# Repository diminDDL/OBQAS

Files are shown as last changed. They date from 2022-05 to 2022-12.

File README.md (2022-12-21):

# OBQAS
Open Battery Quantification and Analysis System

A high efficiency high power imax alternative.

Features include:

* up to 5 Li-ion cells (22 Vout max)

Supported battery types:
* Li-ion (with balancing)
* Ni-mh
* Ni-cd
* Pb
* More...

Ratings:
* Maximum output voltage - 22V
* Maximum charging current - 5A
* Maximum charging power: ~100W

Discharge:
* Maximum input voltage - 22V
* Maximum discharging current - 3A (up to 5A with a better MOSFET)
* Maximum discharging power: ~75W

Input voltage:
12-24V

Topology:
buck-boost synchronous (TPS55288)

Additional features:
20x4 display with encoder
USB-C for data logging and remote control/outputs 5V 1A
SD card holds configuration parameters/standalone data logging
Thermocopule for battery monitoring
ESP32 - WiFI/BLE

### Pictures
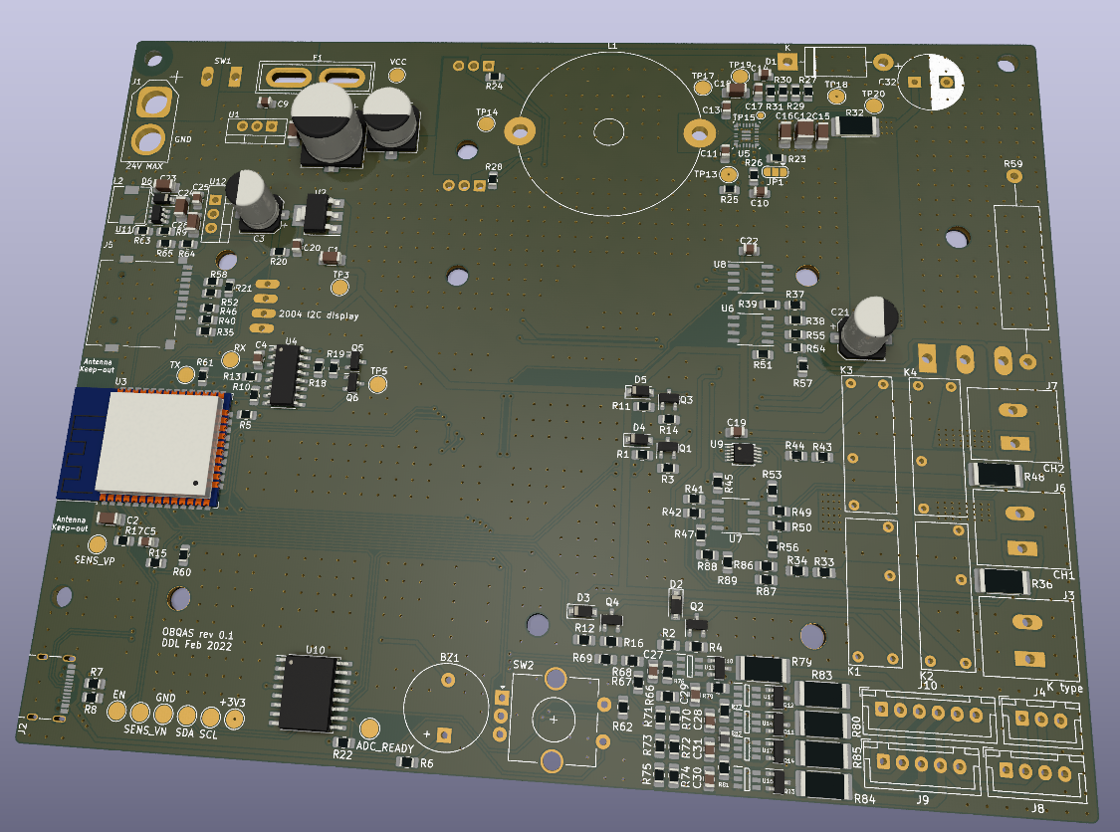
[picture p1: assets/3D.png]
3D render


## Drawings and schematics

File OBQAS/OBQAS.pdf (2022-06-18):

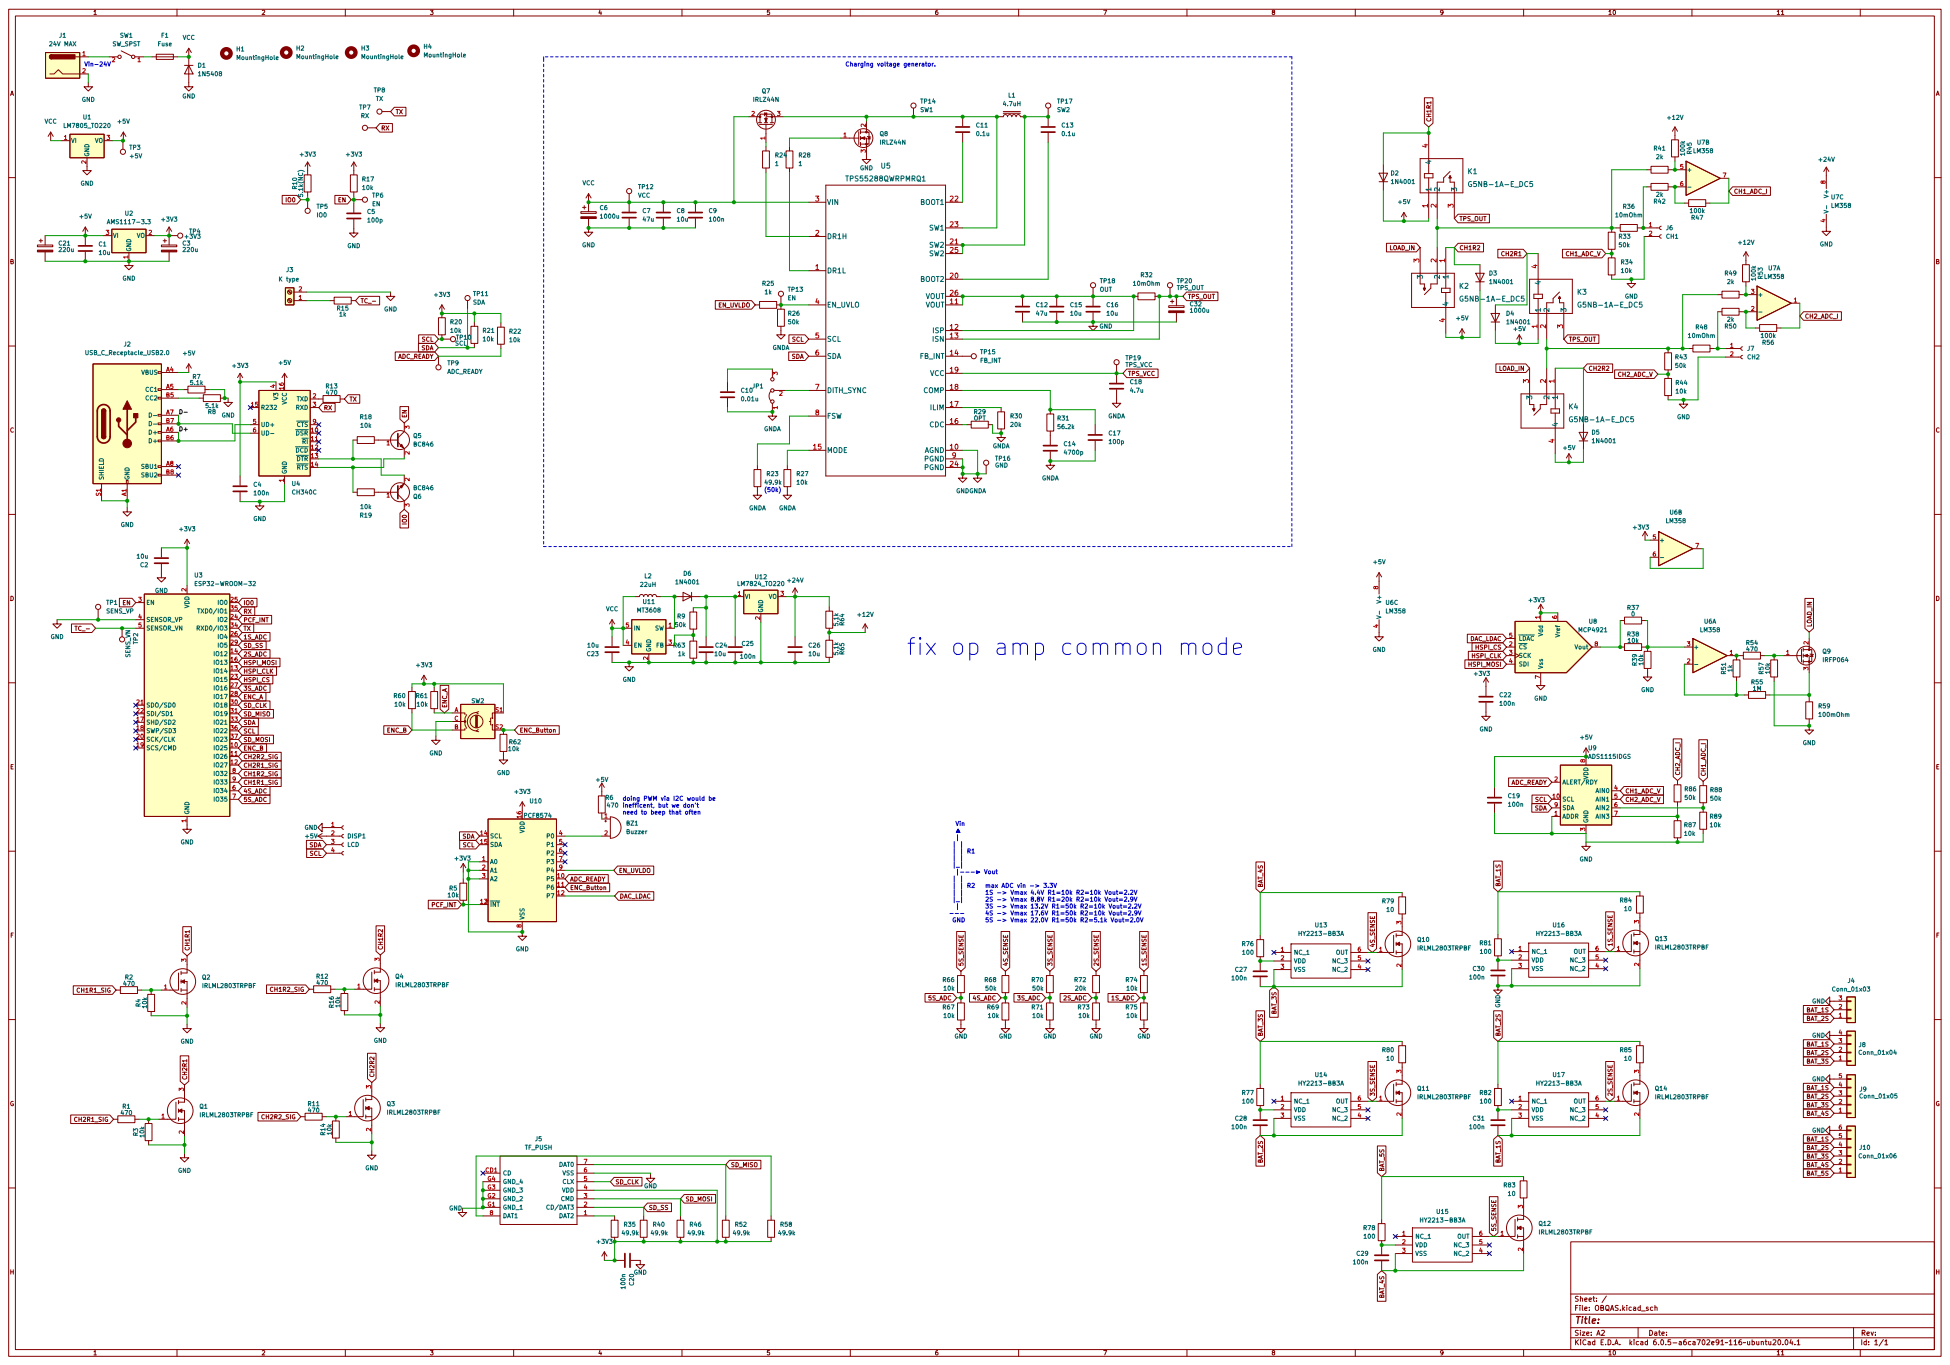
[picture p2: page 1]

1 ~{DSR}10 ~{RI}11 ~{DCD}12 ~{DTR}13 ~{RTS}14 R232 15 VCC 16 TXD 2 RXD 3 V3

2 SCK/CLK 20 SDO/SD0 21 SDI/SD1 22

GND fix op amp common mode

doing PWM via I2C would be
inefficent, but we don't need to beep that often

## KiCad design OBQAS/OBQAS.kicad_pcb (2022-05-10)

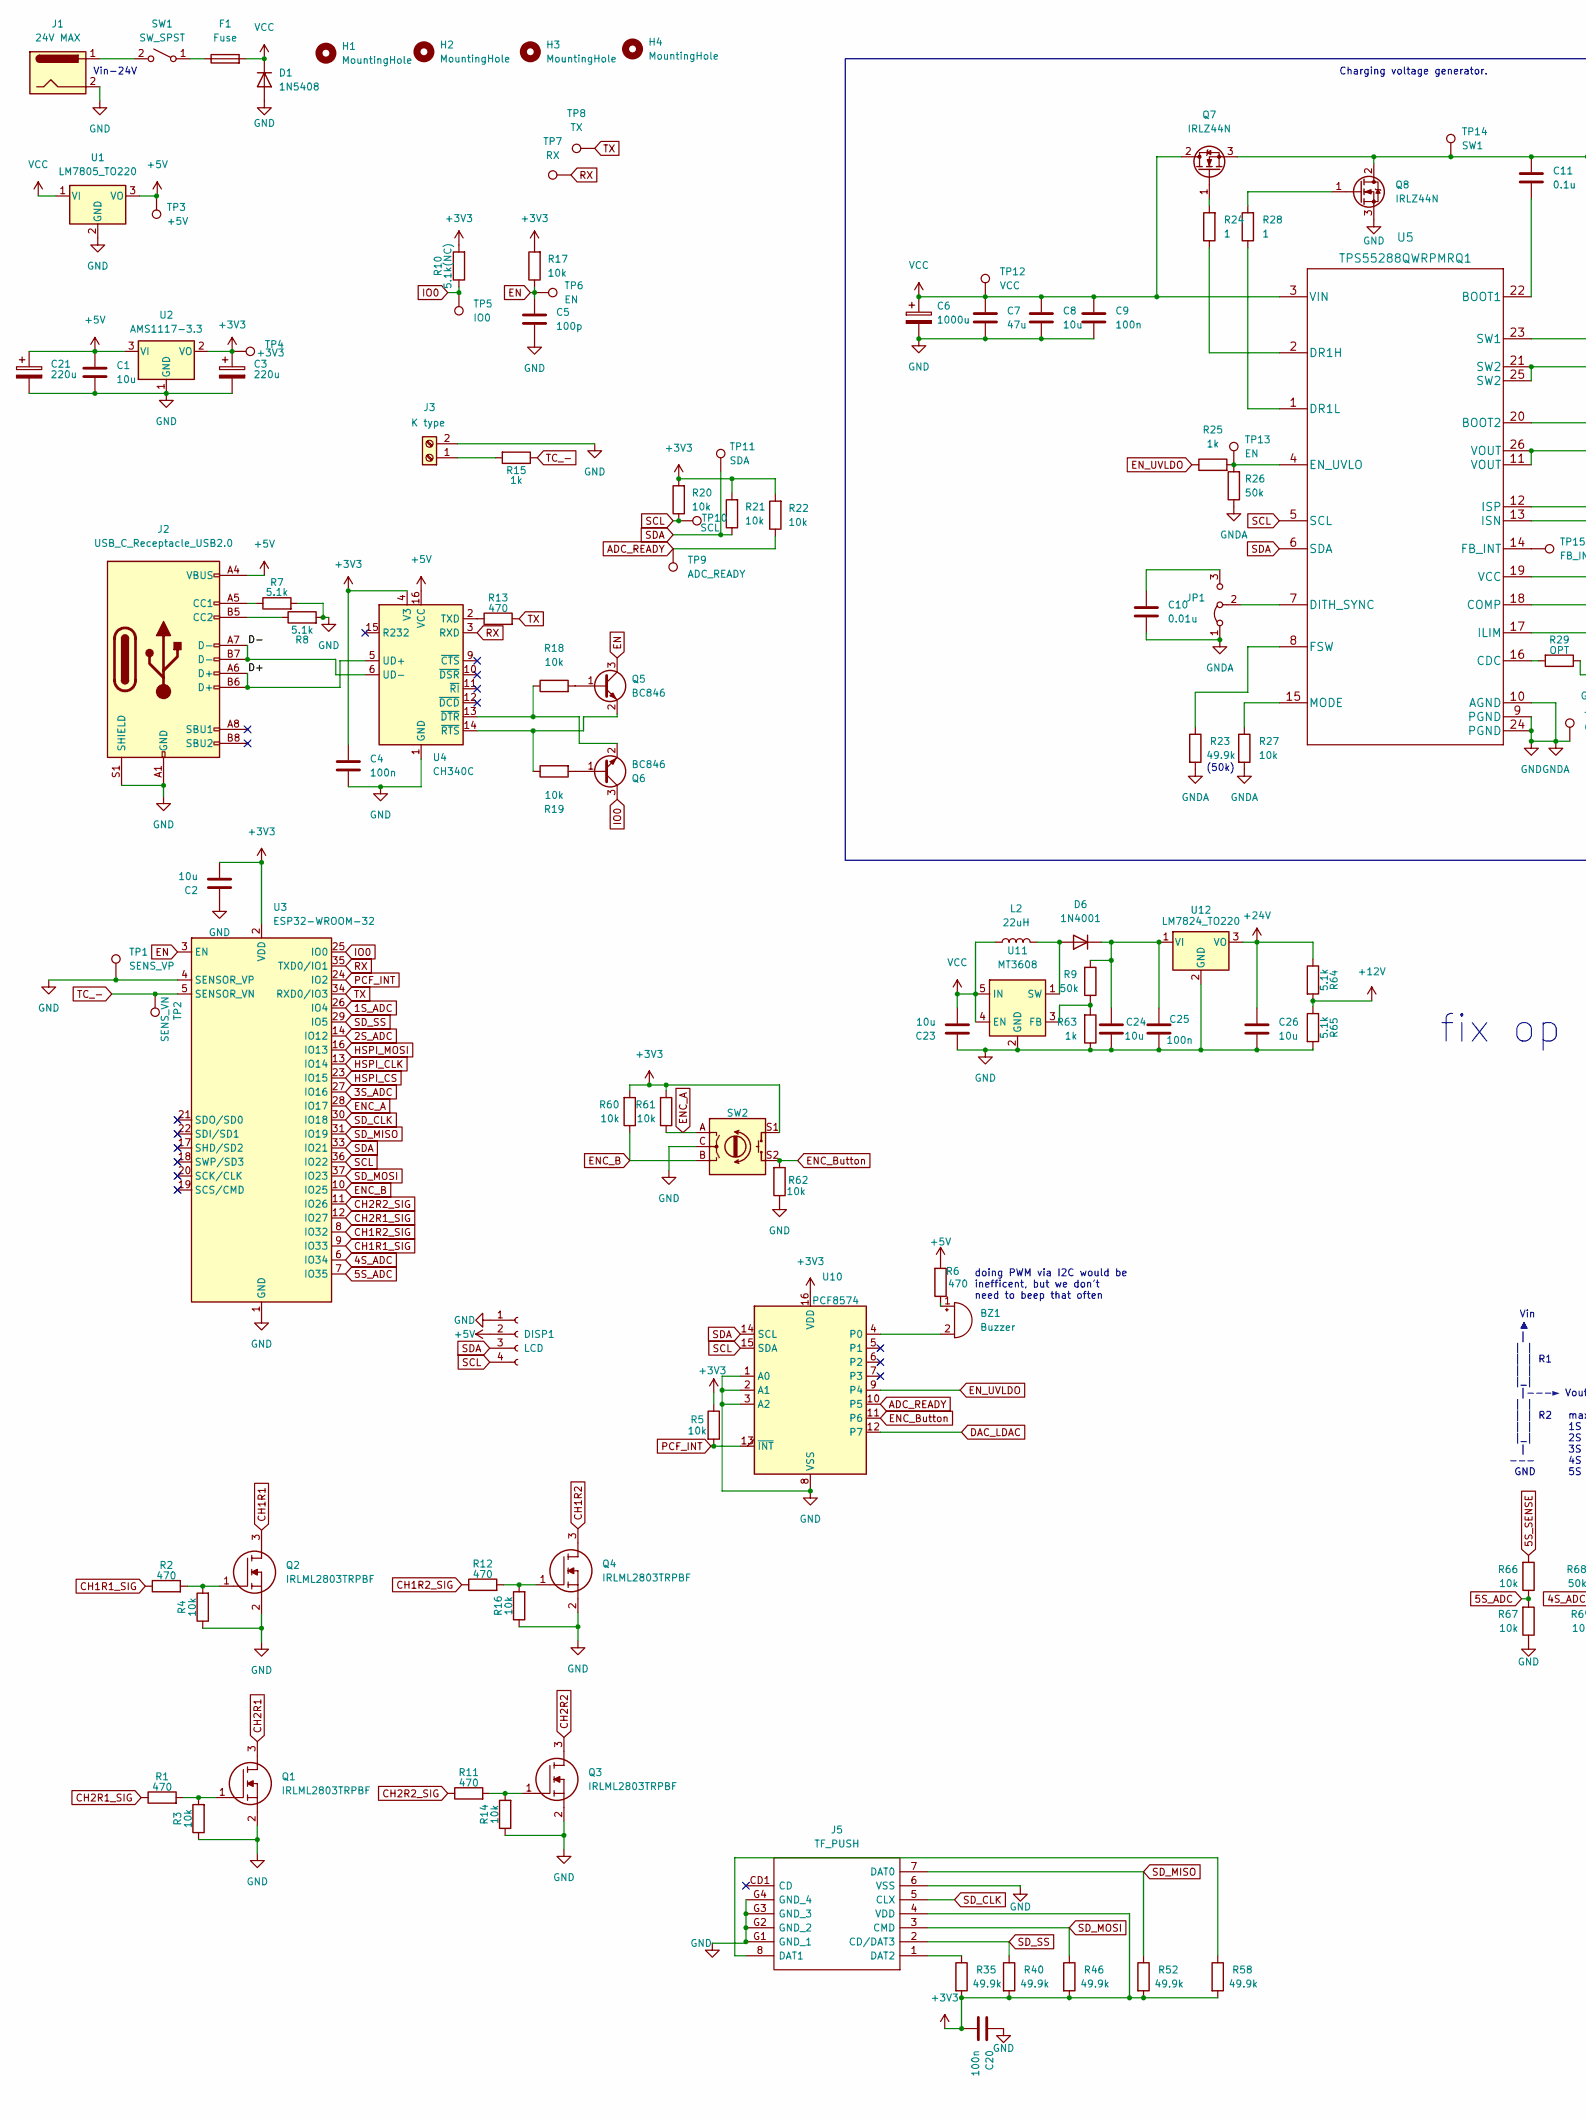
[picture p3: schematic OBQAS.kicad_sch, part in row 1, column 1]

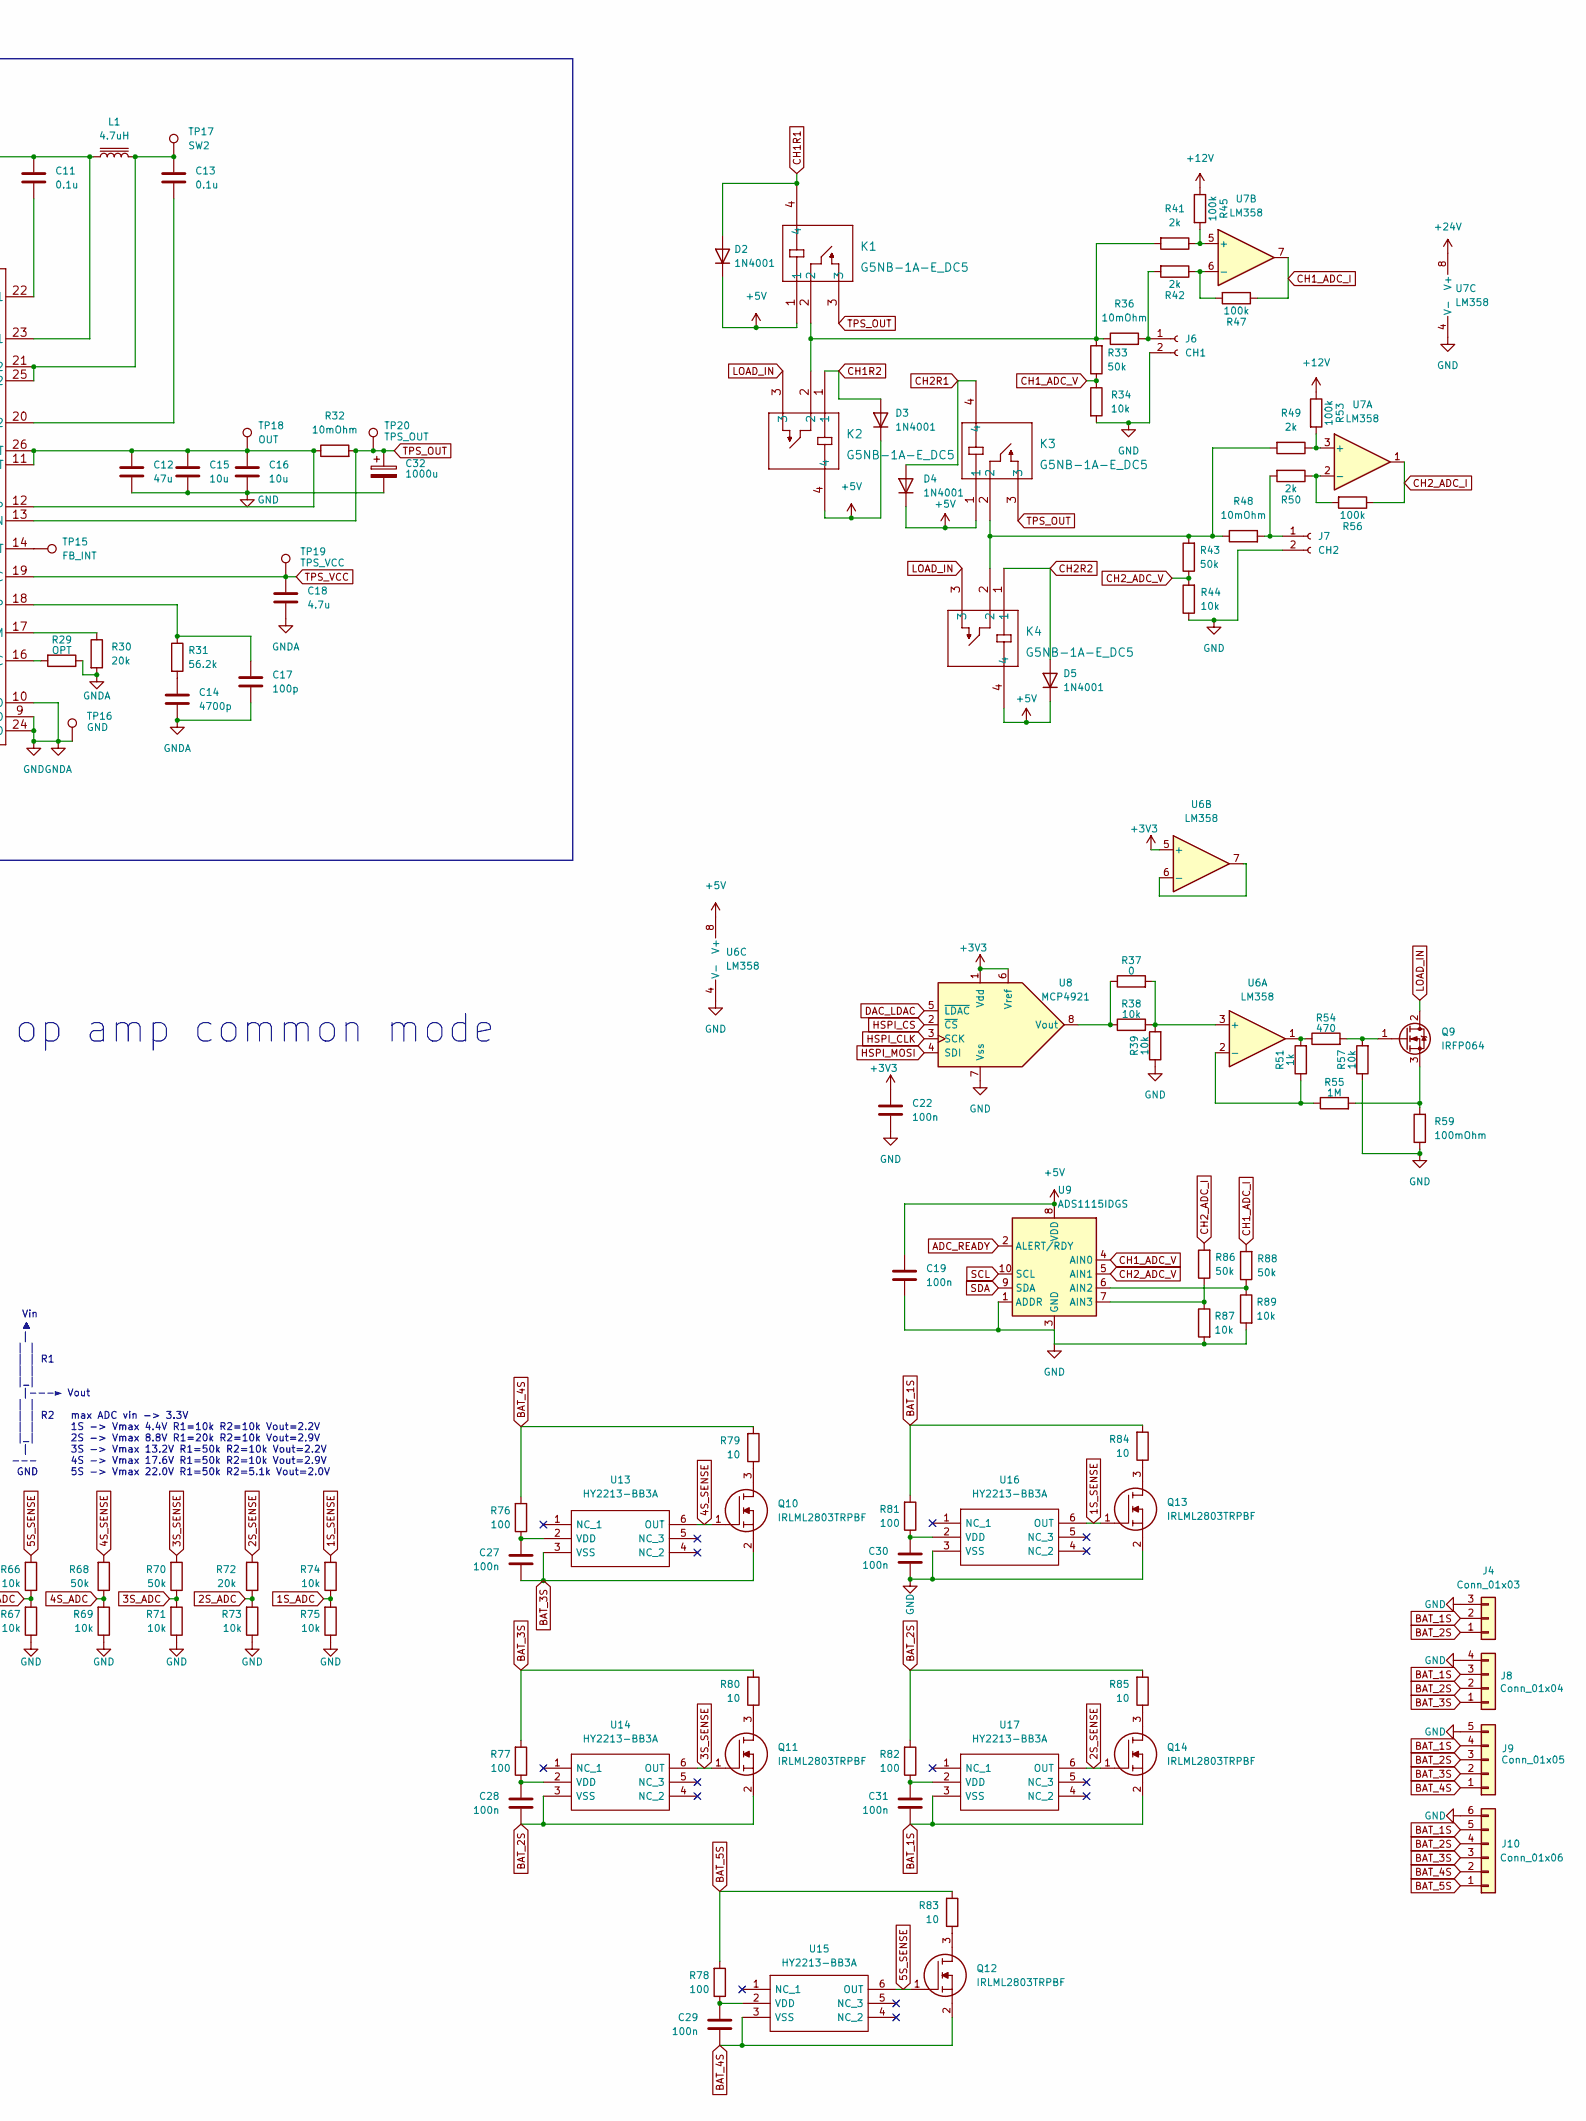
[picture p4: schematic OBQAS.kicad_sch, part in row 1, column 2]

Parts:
BZ1: Buzzer; Buzzer_12x9.5RM7.6
C1, C2, C8, C15, C16, C23, C24, C26: 10u; C_1206_3216Metric_Pad1.33x1.80mm_HandSolder
C3, C21: 220u; CP_Elec_6.3x9.9
C4, C9, C19, C20, C22, C25, C27, C28, C29, C30, C31: 100n; C_0805_2012Metric_Pad1.18x1.45mm_HandSolder
C5, C17: 100p; C_0805_2012Metric_Pad1.18x1.45mm_HandSolder
C6: 1000u; CP_Elec_10x10
C7: 47u; CP_Elec_8x6.9
C10: 0.01u; C_0805_2012Metric_Pad1.18x1.45mm_HandSolder
C11, C13: 0.1u; C_0805_2012Metric_Pad1.18x1.45mm_HandSolder
C12: 47u; C_1210_3225Metric_Pad1.33x2.70mm_HandSolder
C14: 4700p; C_0805_2012Metric_Pad1.18x1.45mm_HandSolder
C18: 4.7u; C_1206_3216Metric_Pad1.33x1.80mm_HandSolder
C32: 1000u; CP_Radial_D10.0mm_P5.00mm
D1: 1N5408; D_DO-201AD_P15.24mm_Horizontal
D2, D3, D4, D5, D6: 1N4001; D_SOD-123
DISP1: LCD; LCD-20x4
F1: Fuse; Fuse_Blade_ATO_directSolder
H1, H2, H3, H4: MountingHole; MountingHole_3.2mm_M3
J1: 24V MAX; AMASS_XT60-F_1x02_P7.20mm_Vertical
J2: USB_C_Receptacle_USB2.0; USB_C_Receptacle_Palconn_UTC16-G
J3: K type; TerminalBlock_Altech_AK300-2_P5.00mm
J4: Conn_01x03; JST_XH_B3B-XH-A_1x03_P2.50mm_Vertical
J5: TF_PUSH; TFPUSH; Manufacturer_Part_Number TF PUSH
J6: CH1; TerminalBlock_Altech_AK300-2_P5.00mm
J7: CH2; TerminalBlock_Altech_AK300-2_P5.00mm
J8: Conn_01x04; JST_XH_B4B-XH-A_1x04_P2.50mm_Vertical
J9: Conn_01x05; JST_XH_B5B-XH-A_1x05_P2.50mm_Vertical
J10: Conn_01x06; JST_XH_B6B-XH-A_1x06_P2.50mm_Vertical
JP1: Jumper_3_Bridged12; SolderJumper-3_P1.3mm_Bridged12_RoundedPad1.0x1.5mm
K1, K2, K3, K4: G5NB-1A-E_DC5; G5NB-1A-E DC5
L1: 4.7uH; L_Radial_D29.8mm_P29.30mm_Murata_1400series
L2: 22uH; L_6.3x6.3_H3
Q1, Q2, Q3, Q4, Q10, Q11, Q12, Q13, Q14: IRLML2803TRPBF; SOT-23; Manufacturer_Part_Number IRLML2803TRPBF; Mouser Part Number 942-IRLML2803TRPBF
Q5, Q6: BC846; SOT-23
Q7, Q8: IRLZ44N; TO-220F-3_Horizontal_TabUp
Q9: IRFP064; TO-247-3_Horizontal_TabUp
R1, R2, R6, R11, R12, R13, R54: 470; R_0805_2012Metric_Pad1.20x1.40mm_HandSolder
R3, R4, R5, R14, R16, R17, R18, R19, R20, R21, R22, R27, R34, R38, R39, R44, R57, R60, R61, R62, R66, R67, R69, R71, R73, R74, R75, R87, R89: 10k; R_0805_2012Metric_Pad1.20x1.40mm_HandSolder
R7, R8, R64, R65: 5.1k; R_0805_2012Metric_Pad1.20x1.40mm_HandSolder
R9, R26, R33, R43, R68, R70, R86, R88: 50k; R_0805_2012Metric_Pad1.20x1.40mm_HandSolder
R10: 5.1k(NC); R_0805_2012Metric_Pad1.20x1.40mm_HandSolder
R15, R25, R51, R63: 1k; R_0805_2012Metric_Pad1.20x1.40mm_HandSolder
R23, R35, R40, R46, R52, R58: 49.9k; R_0805_2012Metric_Pad1.20x1.40mm_HandSolder
R24, R28: 1; R_0805_2012Metric_Pad1.20x1.40mm_HandSolder
R29: OPT; R_0805_2012Metric_Pad1.20x1.40mm_HandSolder
R30, R72: 20k; R_0805_2012Metric_Pad1.20x1.40mm_HandSolder
R31: 56.2k; R_0805_2012Metric_Pad1.20x1.40mm_HandSolder
R32, R36, R48: 10mOhm; R_2512_6332Metric_Pad1.40x3.35mm_HandSolder
R37: 0; R_0805_2012Metric_Pad1.20x1.40mm_HandSolder
R41, R42, R49, R50: 2k; R_0805_2012Metric_Pad1.20x1.40mm_HandSolder
R45, R47, R53, R56: 100k; R_0805_2012Metric_Pad1.20x1.40mm_HandSolder
R55: 1M; R_0805_2012Metric_Pad1.20x1.40mm_HandSolder
R59: 100mOhm; R_Axial_Power_L20.0mm_W6.4mm_P30.48mm
R76, R77, R78, R81: 100; R_0805_2012Metric_Pad1.20x1.40mm_HandSolder
R79, R80, R83, R84, R85: 10; R_2512_6332Metric_Pad1.40x3.35mm_HandSolder
R82: 100; L_0805_2012Metric_Pad1.15x1.40mm_HandSolder
SW1: SW_SPST; TerminalBlock_Altech_AK300-2_P5.00mm
SW2: Enc; RotaryEncoder_Alps_EC11E-Switch_Vertical_H20mm_CircularMoun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
TP1: SENS_VP; TestPoint_Pad_D2.5mm
TP2: SENS_VN; TestPoint_Pad_D2.5mm
TP3: +5V; TestPoint_Pad_D2.5mm
TP4: +3V3; TestPoint_Pad_D2.5mm
TP5: IO0; TestPoint_Pad_D2.5mm
TP6, TP13: EN; TestPoint_Pad_D2.5mm
TP7: RX; TestPoint_Pad_D2.5mm
TP8: TX; TestPoint_Pad_D2.5mm
TP9: ADC_READY; TestPoint_Pad_D2.5mm
TP10: SCL; TestPoint_Pad_D2.5mm
TP11: SDA; TestPoint_Pad_D2.5mm
TP12: VCC; TestPoint_Pad_D2.5mm
TP14: SW1; TestPoint_Pad_D2.5mm
TP15: FB_INT; TestPoint_Pad_D1.0mm
TP16: GND; TestPoint_Pad_D2.5mm
TP17: SW2; TestPoint_Pad_D2.5mm
TP18: OUT; TestPoint_Pad_D2.5mm
TP19: TPS_VCC; TestPoint_Pad_D2.5mm
TP20: TPS_OUT; TestPoint_Pad_D2.5mm
U1: LM7805_TO220; TO-220-3_Vertical
U2: AMS1117-3.3; SOT-223-3_TabPin2
U3: ESP32-WROOM-32
U4: CH340C; SOIC-16_3.9x9.9mm_P1.27mm
U5: TPS55288QWRPMRQ1
U6, U7: LM358; SO-8_3.9x4.9mm_P1.27mm
U8: MCP4921; SO-8_3.9x4.9mm_P1.27mm
U9: ADS1115IDGS; TSSOP-10_3x3mm_P0.5mm
U10: PCF8574; SOIC-16W_7.5x10.3mm_P1.27mm
U11: MT3608; SOT-23-6
U12: LM7824_TO220; TO-220-3_Vertical
U13, U14, U15, U16, U17: HY2213-BB3A; SOT95P280X140-6N; Manufacturer_Part_Number HY2213-BB3A

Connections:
1S_ADC: R74.1, R75.2, U3.26 (IO4)
1S_SENSE: Q13.1, R74.2, U16.6 (OUT)
2S_ADC: R72.1, R73.2, U3.14 (IO12)
2S_SENSE: Q14.1, R72.2, U17.6 (OUT)
3S_ADC: R70.1, R71.2, U3.27 (IO16)
3S_SENSE: Q11.1, R70.2, U14.6 (OUT)
4S_ADC: R68.1, R69.2, U3.6 (IO34)
4S_SENSE: Q10.1, R68.2, U13.6 (OUT)
5S_ADC: R66.1, R67.2, U3.7 (IO35)
5S_SENSE: Q12.1, R66.2, U15.6 (OUT)
+3V3: C2.2, C3.1, C4.1, C20.2, C22.1, J5.4 (VDD), R5.1, R10.2, R17.2, R20.2, R21.2, R22.2, R35.2, R40.2, R46.2, R52.2, R58.2, R60.2, R61.2, SW2.S1, TP4.1, U2.2 (VO), U3.2 (VDD), U4.4 (V3), U6.5 (+), U8.1 (Vdd), U8.6 (Vref), U10.16 (VDD)
+5V: C1.1, C19.1, C21.1, D2.1 (K), D3.1 (K), D4.1 (K), D5.1 (K), DISP1.2, J2.A4 (VBUS), J2.A9 (VBUS), J2.B4 (VBUS), J2.B9 (VBUS), K1.1, K2.4, K3.1, K4.4, R6.2, TP3.1, U1.3 (VO), U2.3 (VI), U4.16 (VCC), U6.8 (V+), U9.8 (VDD)
+12V: R45.1, R53.1, R64.2, R65.1
+24V: C26.1, R64.1, U7.8 (V+), U12.3 (VO)
/D+: J2.A6 (D+), J2.B6 (D+), U4.5 (UD+)
/D-: J2.A7 (D-), J2.B7 (D-), U4.6 (UD-)
ADC_READY: R22.1, TP9.1, U9.2 (ALERT/RDY), U10.10 (P5)
BAT_1S: C31.2, J4.2, J8.3, J9.4, J10.5, Q14.2, R81.2, R84.2, U17.3 (VSS)
BAT_2S: C28.2, J4.1, J8.2, J9.3, J10.4, Q11.2, R82.2, R85.2, U14.3 (VSS)
BAT_3S: C27.2, J8.1, J9.2, J10.3, Q10.2, R77.2, R80.2, U13.3 (VSS)
BAT_4S: C29.2, J9.1, J10.2, Q12.2, R76.2, R79.2, U15.3 (VSS)
BAT_5S: J10.1, R78.2, R83.2
CH1R1: D2.2 (A), K1.4, Q2.3
CH1R1_SIG: R2.1, U3.9 (IO33)
CH1R2: D3.2 (A), K2.1, Q4.3
CH1R2_SIG: R12.1, U3.8 (IO32)
CH1_ADC_I: R47.1, R88.2, U7.7
CH1_ADC_V: R33.1, R34.1, U9.4 (AIN0)
CH2R1: D4.2 (A), K3.4, Q1.3
CH2R1_SIG: R1.1, U3.12 (IO27)
CH2R2: D5.2 (A), K4.1, Q3.3
CH2R2_SIG: R11.1, U3.11 (IO26)
CH2_ADC_I: R56.1, R86.2, U7.1
CH2_ADC_V: R43.1, R44.2, U9.5 (AIN1)
DAC_LDAC: U8.5 (~LDAC), U10.12 (P7)
EN: C5.1, Q5.3 (C), R17.1, TP6.1, U3.3 (EN)
ENC_A: R61.1, SW2.A, U3.28 (IO17)
ENC_B: R60.1, SW2.B, U3.10 (IO25)
ENC_Button: R62.2, SW2.S2, U10.11 (P6)
EN_UVLDO: R25.1, U10.9 (P4)
GND: C1.2, C2.1, C3.2, C4.2, C5.2, C6.2, C7.2, C8.2, C9.2, C10.2, C12.2, C14.2, C15.2, C16.2, C17.2, C18.2, C19.2, C20.1, C21.2, C22.2, C23.1, C24.2, C25.2, C26.2, C30.2, C32.2, D1.2 (A), DISP1.1, J1.2, J2.A1 (GND), J2.A12 (GND), J2.B1 (GND), J2.B12 (GND), J2.S1 (SHIELD), J3.2, J4.3, J5.6 (VSS), J5.G1 (GND_1), J5.G2 (GND_2), J5.G3 (GND_3), J5.G4 (GND_4), J6.2, J7.2, J8.4, J9.5, J10.6, JP1.1 (A), Q1.2, Q2.2, Q3.2, Q4.2, Q8.3 (S), Q13.2, R3.1, R4.1, R7.2, R8.2, R14.1, R16.1, R23.2, R26.1, R27.2, R29.1, R30.2, R34.2, R39.1, R44.1, R57.1, R59.1, R62.1, R63.1, R65.2, R67.1, R69.1, R71.1, R73.1, R75.1, R87.2, R89.2, SW2.C, TP1.1, TP16.1, U1.2 (GND), U2.1 (GND), U3.1 (GND), U3.4 (SENSOR_VP), U3.15 (GND), U3.38 (GND), U3.39 (GND), U4.1 (GND), U5.9 (PGND), U5.10 (AGND), U5.24 (PGND), U6.4 (V-), U7.4 (V-), U8.7 (Vss), U9.1 (ADDR), U9.3 (GND), U10.1 (A0), U10.2 (A1), U10.3 (A2), U10.8 (VSS), U11.2 (GND), U12.2 (GND), U16.3 (VSS)
HSPI_CLK: U3.13 (IO14), U8.3 (SCK)
HSPI_CS: U3.23 (IO15), U8.2 (~CS)
HSPI_MOSI: U3.16 (IO13), U8.4 (SDI)
IO0: Q6.3 (C), R10.1, TP5.1, U3.25 (IO0)
LOAD_IN: K2.3, K4.3, Q9.2 (D)
unnamed: BZ1.1 (-), R6.1
unnamed: BZ1.2 (+), U10.4 (P0)
unnamed: C10.1, JP1.3 (B)
unnamed: C11.1, L1.1, Q7.3 (S), Q8.2 (D), TP14.1, U5.23 (SW1)
unnamed: C11.2, U5.22 (BOOT1)
unnamed: C12.1, C15.1, C16.1, R32.1, TP18.1, U5.11 (VOUT), U5.12 (ISP), U5.26 (VOUT)
unnamed: C13.1, L1.2, TP17.1, U5.21 (SW2), U5.25 (SW2)
unnamed: C13.2, U5.20 (BOOT2)
unnamed: C14.1, R31.2
unnamed: C17.1, R31.1, U5.18 (COMP)
unnamed: C24.1, C25.1, D6.1 (K), R9.2, U12.1 (VI)
unnamed: C27.1, R76.1, U13.2 (VDD)
unnamed: C28.1, R77.1, U14.2 (VDD)
unnamed: C29.1, R78.1, U15.2 (VDD)
unnamed: C30.1, R81.1, U16.2 (VDD)
unnamed: C31.1, R82.1, U17.2 (VDD)
unnamed: D6.2 (A), L2.2, U11.1 (SW)
unnamed: F1.1, SW1.1 (A)
unnamed: J1.1, SW1.2 (B)
unnamed: J2.A5 (CC1), R7.1
unnamed: J2.B5 (CC2), R8.1
unnamed: J3.1, R15.2
unnamed: J5.1 (DAT2), R35.1
unnamed: J5.8 (DAT1), R58.1
unnamed: J6.1, R36.2, R42.2
unnamed: J7.1, R48.2, R50.2
unnamed: JP1.2 (C), U5.7 (DITH_SYNC)
unnamed: K1.2, K2.2, R33.2, R36.1, R41.2
unnamed: K3.2, K4.2, R43.2, R48.1, R49.2
unnamed: Q1.1, R1.2, R3.2
unnamed: Q2.1, R2.2, R4.2
unnamed: Q3.1, R11.2, R14.2
unnamed: Q4.1, R12.2, R16.2
unnamed: Q5.1 (B), R18.2
unnamed: Q5.2 (E), R19.1, U4.14 (~RTS)
unnamed: Q6.1 (B), R19.2
unnamed: Q6.2 (E), R18.1, U4.13 (~DTR)
unnamed: Q7.1 (G), R24.2
unnamed: Q8.1 (G), R28.2
unnamed: Q9.1 (G), R54.2, R57.2
unnamed: Q9.3 (S), R55.2, R59.2
unnamed: Q10.3, R79.1
unnamed: Q11.3, R80.1
unnamed: Q12.3, R83.1
unnamed: Q13.3, R84.1
unnamed: Q14.3, R85.1
unnamed: R13.1, U4.2 (TXD)
unnamed: R23.1, U5.8 (FSW)
unnamed: R24.1, U5.2 (DR1H)
unnamed: R25.2, R26.2, TP13.1, U5.4 (EN_UVLO)
unnamed: R27.1, U5.15 (MODE)
unnamed: R28.1, U5.1 (DR1L)
unnamed: R29.2, U5.16 (CDC)
unnamed: R30.1, U5.17 (ILIM)
unnamed: R37.1, R38.1, U8.8 (Vout)
unnamed: R37.2, R38.2, R39.2, U6.3 (+)
unnamed: R41.1, R45.2, U7.5 (+)
unnamed: R42.1, R47.2, U7.6 (-)
unnamed: R49.1, R53.2, U7.3 (+)
unnamed: R50.1, R56.2, U7.2 (-)
unnamed: R51.1, R55.1, U6.2 (-)
unnamed: R51.2, R54.1, U6.1
unnamed: R9.1, R63.2, U11.3 (FB)
unnamed: R86.1, R87.1, U9.7 (AIN3)
unnamed: R88.1, R89.1, U9.6 (AIN2)
unnamed: TP15.1, U5.14 (FB_INT)
unnamed: U6.6 (-), U6.7
PCF_INT: R5.2, U3.24 (IO2), U10.13 (~INT)
RX: TP7.1, U3.35 (TXD0/IO1), U4.3 (RXD)
SCL: DISP1.4, R20.1, TP10.1, U3.36 (IO22), U5.5 (SCL), U9.10 (SCL), U10.15 (SDA)
SDA: DISP1.3, R21.1, TP11.1, U3.33 (IO21), U5.6 (SDA), U9.9 (SDA), U10.14 (SCL)
SD_CLK: J5.5 (CLX), U3.30 (IO18)
SD_MISO: J5.7 (DAT0), R52.1, U3.31 (IO19)
SD_MOSI: J5.3 (CMD), R46.1, U3.37 (IO23)
SD_SS: J5.2 (CD/DAT3), R40.1, U3.29 (IO5)
TC_-: R15.1, TP2.1, U3.5 (SENSOR_VN)
TPS_OUT: C32.1, K1.3, K3.3, R32.2, TP20.1, U5.13 (ISN)
TPS_VCC: C18.1, TP19.1, U5.19 (VCC)
TX: R13.2, TP8.1, U3.34 (RXD0/IO3)
VCC: C6.1, C7.1, C8.1, C9.1, C23.2, D1.1 (K), F1.2, L2.1, Q7.2 (D), TP12.1, U1.1 (VI), U5.3 (VIN), U11.4 (EN), U11.5 (IN)

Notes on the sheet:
max ADC vin -> 3.3V 1S -> Vmax 4.4V R1=10k R2=10k Vout=2.2V 2S -> Vmax 8.8V R1=20k R2=10k Vout=2.9V 3S -> Vmax 13.2V R1=50k R2=10k Vout=2.2V 4S -> Vmax 17.6V R1=50k R2=10k Vout=2.9V 5S -> Vmax 22.0V R1=50k R2=5.1k Vout=2.0V
(50k)
Vin-24V
Charging voltage generator.
Vin ▲ | | | | | R1 | | |_| |---► Vout | | | | R2 | | |_| | --- GND
fix op amp common mode
doing PWM via I2C would be inefficent, but we don't need to beep that often

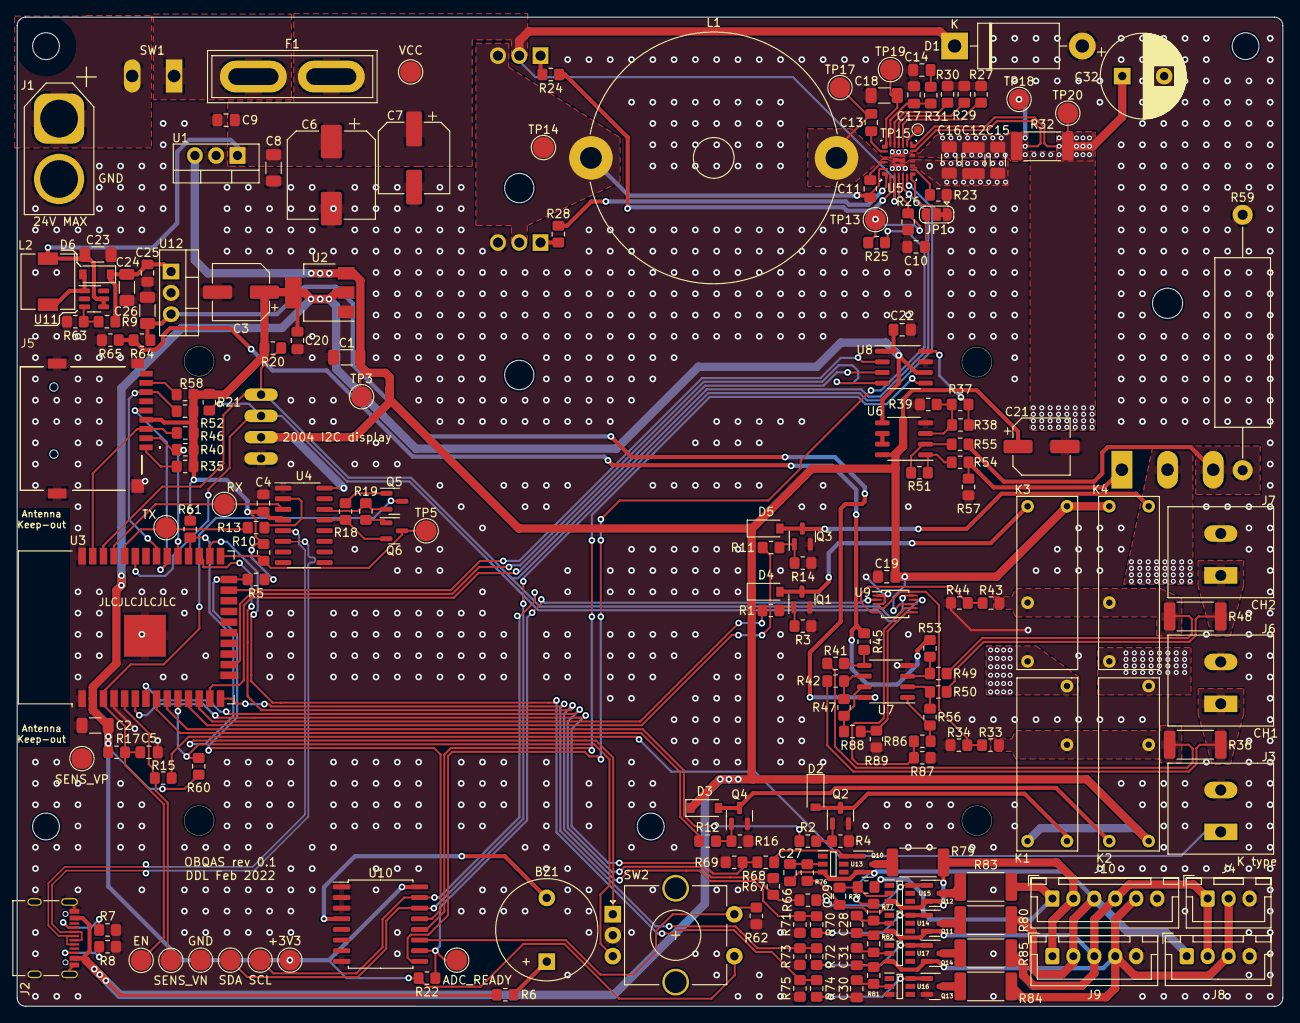
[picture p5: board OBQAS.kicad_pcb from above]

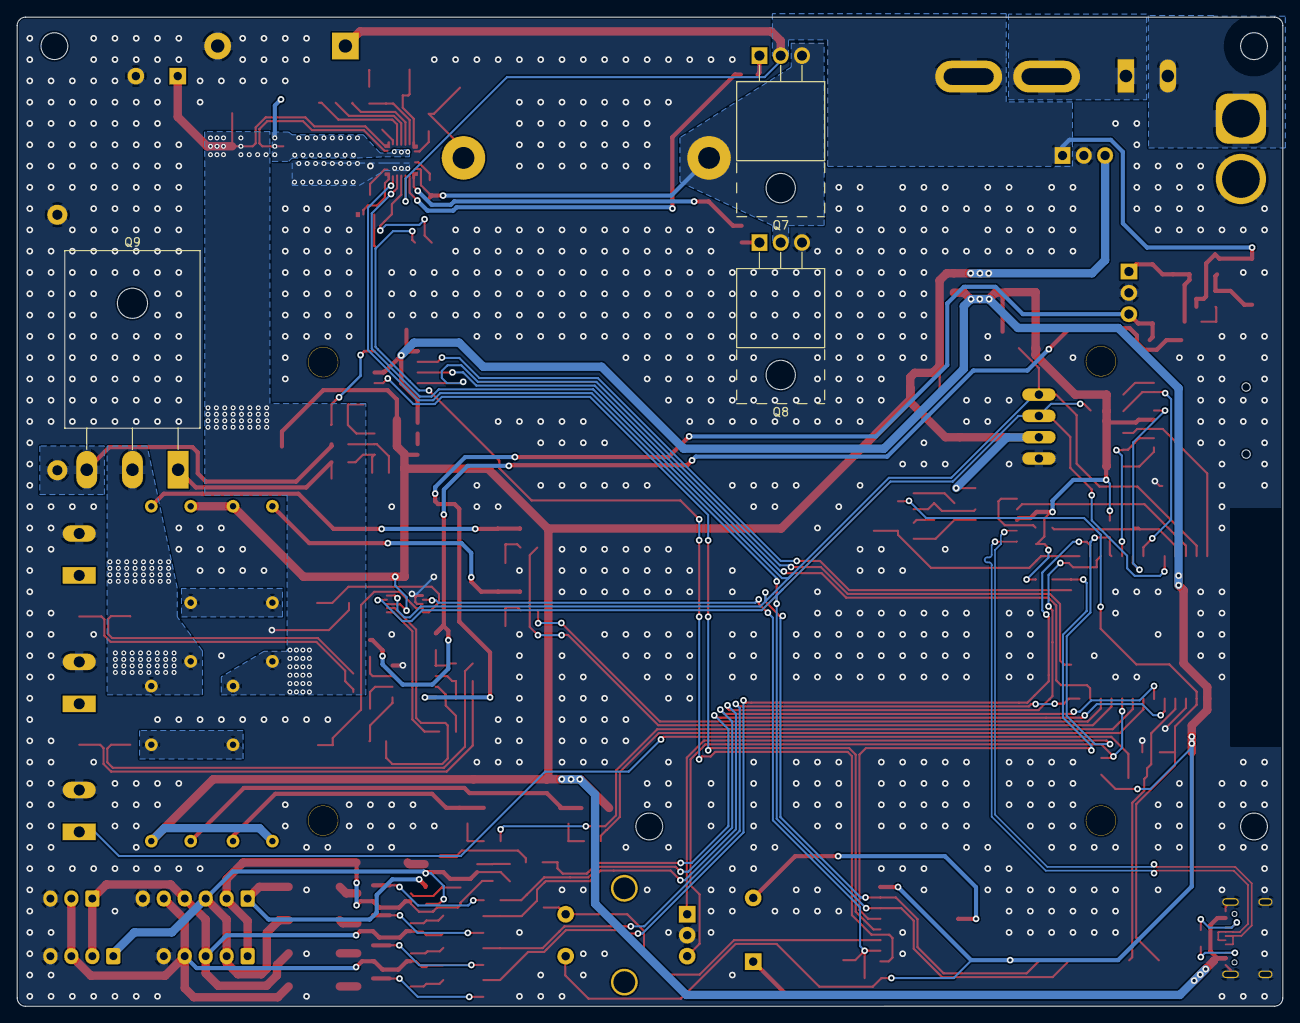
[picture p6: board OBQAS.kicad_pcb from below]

Board: 2 copper layers, 151.0 x 118.0 mm, 204 parts (3 on the bottom side), 126 nets.

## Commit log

2022-01-21 intial schematic design
    [OBQAS.kicad_pcb, OBQAS.kicad_sch]
2022-01-24 continued schematic editing
    [OBQAS.kicad_sch]
2022-01-25 Finished schematic
    [OBQAS.kicad_sch]
2022-01-25 changed SD card
    [OBQAS.kicad_sch]
2022-01-25 added encoder and assigned some footprints
    [OBQAS.kicad_sch]
2022-01-26 beginning of PCB layout
    [OBQAS.kicad_pcb, OBQAS.kicad_sch]
2022-01-27 inital routing complete
    [OBQAS.kicad_pcb, OBQAS.kicad_sch]
2022-01-27 finished layout, doing silkscreen adjustment
    [OBQAS.kicad_pcb, OBQAS.kicad_sch]
2022-01-27 additional schematic changes to accommodate balancing
    [OBQAS.kicad_sch]
2022-02-01 updated schematic with balancing circuit
    [OBQAS.kicad_pcb, OBQAS.kicad_sch]
2022-02-01 finished routing of the new circuit
    [OBQAS.kicad_pcb]
2022-02-02 final PCB
    [OBQAS.kicad_pcb]
2022-02-02 smal tweaks to the PCB
    [OBQAS.kicad_pcb]
2022-02-02 added gerbers
    [OBQAS-B_Cu.gbl, OBQAS-B_Mask.gbs, OBQAS-B_Paste.gbp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]
2022-05-10 minor changes
    [OBQAS.kicad_pcb]
2022-06-18 updated PDF
    [OBQAS.kicad_sch]
